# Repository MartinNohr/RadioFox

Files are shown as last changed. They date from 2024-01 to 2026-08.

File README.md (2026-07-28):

# RadioFox
Ham Radio Fox Software
This is the code for a TTGO T-Display running an SA818V radio. It is used for fox/bunny hunting.
This code requires the phoneDTMF library from here:
https://github.com/Adrianotiger/phoneDTMF
Install as documents/arduino/libraries/phoneDTMF

7/1/2026 The code has been changed to use VS Code with the pio extension loaded. Load the dtmf file into the VS Code lib folder.
The code also now uses espressif version 3.x instead of 2.x. They had introduced a number of breaking changes in version 3.x that resulted in numerous code changes.

7/28/2026 I went back to core 2.0.17. The 3.x one rebooted constantly. I'll spend some time later figureing out why.

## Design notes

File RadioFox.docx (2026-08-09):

# Radio Fox

Using TTGO T1 (T-Display)

# 1 Introduction

## 1.1 Radio Fox History

There is a hobby among amateur radio enthusiasts (AKA Hams) that is known as fox hunting or sometimes as bunny hunting. It is played by hiding a transmitter that transmits periodically and is then silent until it is time to transmit again. This cycle repeats. Teams use radio receivers with directional antennas to find the transmitter. The technique is called triangulation. The first team to find the transmitter wins. Sometimes the transmitter is moved periodically to make the game more challenging, this is called a walking fox.

Many of these radios are homemade using handheld radios and timers. This device is a single PCB (printed circuit board) using an esp32 (Arduino) computer with a display. There are two 18650 batteries with a charging circuit and an SA818 shortwave transceiver module on the PCB. A rotary push button dial is used to set the various parameters for the fox. These parameters include transmit time, pause time, frequency settings, audio, morse code ID, various other radio settings, and a variety of system settings for the fox device.

The Bionics company manufactures several types of Fox radios. I had never heard of them until I had this project working, so I can’t claim to be inspired by any of their designs. Sven Schumacher (VE6IDK) proposed this project to me in 2023, at which time I suggested using the TTGO T-Display esp32 module. I had used this device in a previous project, my Magic Image Wand, so I already had a nice menu system that would be easy to adapt to this project. It also featured code to handle a micro-SD card which could be used to store configuration files and music/tone files.

A link to this file can be found here: https://www.youtube.com/watch?v=oTXZL2KgMQE

## 1.2 Antenna

Any 50-ohm antenna designed for the VHF range is acceptable. Please remember to connect the antenna before transmitting, it is safest to have the proper load connected to the radio chip. You can also connect a 50-ohm dummy load for testing purposes to avoid sending radio waves out into the air!

## 1.3 Initial Setup

The first thing to enter is the Call Sign. Remember that you should not be transmitting without sending your call sign out periodically. The radio cycles between Call Sign and Beacon (whatever text you want) and the audio if a file has been selected. The audio can be wav, mp3, or the txt files which generate tones. The Beacon and Call Sign are sent out as morse code. A future revision of the PCB is being considered that will have an audio chip so higher quality sound recordings can be sent. The speed and pitch of the morse code can be adjusted.

The Beacon text is often something that will identify this radio, especially if there are more fox radios in the same neighborhood.

## 1.4 Charging Issues

The device is charged using the USB-C connector. There is a flaw on the PCB that requires a USB-A to USB-C cable. This has been fixed in version 1.11 of the PCB so that USB-C to USB-C cables will also work.

## 1.5 Beacon Mode

Version 1.06 adds a beacon mode that limits the allowed frequency range. The system must be powered by an external power supply connected to the USB C charging port if you want it to keep running for days, weeks or longer. This Beacon mode should not be confused with the Beacon text that is transmitted periodically.

## 1.6 Source Code

The firmware source code consists of C and C++. The source code can be found at MartinNohr/RadioFox: Ham Radio Fox Software (https://github.com/MartinNohr/RadioFox)

VS Code IDE with the pioarduino extension is used for compiling the code. The libraries used are listed in the platformio.ini file.

If you just want to flash the bin files from the GitHub site, I have tried several websites, and this one worked the best: ESP Terminator | Browser-Based Firmware Flasher (https://espterminator.com/)

Use the factory bin file for versions before 1.15. The factory file can actually be used anytime. The other bin file is for loading from the SD card.

Steps for using the flash website:

1. Select ESP32
2. Select Device and then select serial port
3. Connect device, it should show connected and the screen will change
4. Select firmware file (the factory one)
5. On the right panel find “flash firmware” and click it
6. Wait patiently, it takes a minute or two
7. Click on “disconnect” button on the left side.

### 1.6.1 Radio Firmware Versions

Version 1.15

- Fixed the update firmware command. It was unfortunately broken in previous versions. It can only be updated by flashing everything. The factory bin file is required for this since the partition table has been changed. The factory bin file is called ./firmware/firmware.factory.bin. This file contains all the partition information, the bootloader and the app code. Use ESP Terminator | Browser-Based Firmware Flasher (https://espterminator.com/) to upload everything. You can also send the esp32 back to me and I will program it for free, just include the postage.

Version 1.14

- Added ability to play WAV and MP3 files. Removed the immediate txstop option as it could leave the audio player in an untidy state. Updated some libraries to the latest versions.

Version 1.13

- Ported the code to espressif core 3.x instead of requiring 2.0.17.

Version 1.12

- Moved latitude and longitude menu items to be right below the “Send GPS:” menu item. They were below the “TX:” menu which was confusing. The TX frequency item was moved right below the TX Power and before the beacon mode item.
- I also corrected the documentation that the power output is 1 or 0.5 Watts for high and low power settings.

Version 1.11

- Added ability to send manually entered GPS coordinates when in beacon mode.

Version 1.10

- Added main menu entries to return to the main run screen. The long press still works.

Version 1.09

- Moved the active time display to the end of the second line on the main display. Bug 32, when the audio file was selected, the last line overwrote the bottom of the display.

Version 1.08

- Show the active run time on the main display in hours, minutes, and seconds. This time is reset on boot, and just keeps track of the time used for sending and pausing.

Version 1.07

- Change "Beacon Frequency Mode" in menus to "Beacon Frequency".

Version 1.06

- Added a switch to limit the frequency range to that allowed for beacon use in ITU region 2. The range is 144.276-144.300 MHz.

Version 1.05

- Added adjustable morse pitch, from 300 to 3000 Hz.

Version 1.04

- Fixed crash when no SD card found.

Version 1.03

- Fixed hang problem #26. Short TX time and B0 pressed caused the display to stop updating.

Version 1.02

- Changed prompts from BTN0/1 to B0/1 to match the labels on the case.

Version 1.01

- Made TX red dot larger. Show DTMF characters in green on the bottom. (not tested yet).

Version 1.00

- This is the initial version when this document was first created. The software is considered mostly complete.

# 2 The Hardware

## 2.1 PCB

The Fox is a single PCB that includes an 18650 battery holder that can have 1 or 2 batteries. You can choose 1 or 2 since they are connected in parallel. The button top style batteries are required. The flat top batteries will not work. Also note that the size standard is not always followed and some batteries will not fit. If that is the case try a different pair. The best batteries I have found are from www.liionwholesale.com. The batteries I use are found here: Protected 3400mAh 10A 18650 Button Top Battery - Wholesale Discount – Liion Wholesale Batteries (https://liionwholesale.com/collections/batteries/products/protected-3400mah-10a-18650-button-top-battery-wholesale-discount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) .

There is a USB C connector on the left edge used for charging the batteries. Above that is a micro-SD slot. The SD card holds tone files and saved settings files. It can also be used to load new firmware onto the TTGO chip. There is also a USB C connector on the TTGO. It is used for downloading firmware or debugging operations. It might also be used for serial communications in a future firmware release. It is not used for charging the batteries.

## 2.2 Radio

The radio functions are handled by the SA818-V on the top right. There are vents in the case to allow cooling as this module can become quite hot when transmitting at high power for longer timer intervals. Transmitting longer than one minute is not recommended. High power is about 1W and low power is about 0.5W. These powers are according to the data sheet and may not be entirely accurate. I have not measured them with a power meter. Make sure a suitable antenna is connected to avoid damage to the radio circuit.

## 2.3 Batteries

The 18650 batteries must be button top style and protection is recommended. The 18650 battery length is a very loose standard, and some batteries may not fit. Too long and they cannot be used. Too short, it might be possible to bend the contacts on the battery holder negative side. The battery holder is polarized to prevent insertion in the wrong direction. Do not defeat the feature or magic blue smoke may appear from the PCB!

## 2.4 Micro SD Card

The SD card holds the tone, mp3, and wav files. You can also put the RadioFox.bin file on there for updating the firmware. Note that updating only works for version 1.15 and later. The latest firmware file is found on the GitHub site. It is at ./firmware/firmware.bin and must be renamed on the SD card to RadioFox.bin. See the notes above on version 1.15 and the source code for more information.

Note that the SD card is limited to 32GB. This is a function of the espressif core code for handling files. We hope this will be updated at some point.

# 3 Run Time

The actual runtime depends on the transmitting time and quality of the batteries. There are many deceptively labelled 18650 batteries available. The best ones I have found are made by Panasonic and Sanyo. Using 1 minute transmit, 4 minutes pause, low power setting, and display dimming the Fox Radio ran for 12 hours using Panasonic batteries.

# 4 Tone Files

The tone files are used to play “music” during transmissions. This can be used to identify the Fox, or just to annoy people!

The files are saved as .TXT and simply contain a list of tones to be played. The format is similar the hard coded files from here: robsoncouto/arduino-songs (github.com) (https://github.com/robsoncouto/arduino-songs/tree/master)

The Robson GitHub site has many other example tone files. They are arrays in code but are easily converted to the required text format. Give the file a name and save it on the SD card.

## 4.1 Example Tone File

This is the Tetris theme music

there are two values per note (pitch and duration)

make sure each token ends with a ','

and that the data starts with the tilde which must not be in these comments

LENGTH, %val can be used to set the length of the note, it defaults to 90% and 10% quiet after the note

This can be used for pizzicato notes, LENGTH, 25, for example

~

TEMPO, 145,

LENGTH, 90,

NOTE_E5, 4, NOTE_B4, 8, NOTE_C5, 8, NOTE_D5, 4, NOTE_C5, 8, NOTE_B4, 8,

NOTE_A4, 4, NOTE_A4, 8, NOTE_C5, 8, NOTE_E5, 4, NOTE_D5, 8, NOTE_C5, 8,

NOTE_B4, -4, NOTE_C5, 8, NOTE_D5, 4, NOTE_E5, 4,

NOTE_C5, 4, NOTE_A4, 4, NOTE_A4, 8, NOTE_A4, 4, NOTE_B4, 8, NOTE_C5, 8,

NOTE_D5, -4, NOTE_F5, 8, NOTE_A5, 4, NOTE_G5, 8, NOTE_F5, 8,

NOTE_E5, -4, NOTE_C5, 8, NOTE_E5, 4, NOTE_D5, 8, NOTE_C5, 8,

NOTE_B4, 4, NOTE_B4, 8, NOTE_C5, 8, NOTE_D5, 4, NOTE_E5, 4,

NOTE_C5, 4, NOTE_A4, 4, NOTE_A4, 4, REST, 4,

# 5 Audio Files

It is possible to play MP3 or WAV files instead of the tone files. They are selected through the same menu selection. The radio uses PDM (pulse density modulation) to encode the audio. This is not the best audio quality, but it does allow the use of the existing board design. Better quality would require a proper sound chip on the PCB. This may be done in the future.

# 6 Updating Firmware

The new file must be put on the SD card and named RadioFox.bin. The file is found on the github site in the firmware folder, it is named firmware.bin, it must be renamed and copied to the micro SD card. The system menu has an entry New Version BIN file that will attempt to load this file. Confirmation will be required from the dial, After loading the BIN file can optionally be erased.

There is another file there named firmware.factory.bin. It contains the partition settings needed to update pre 1.15 versions, which are not bin file updateable. It will be necessary to use an esp32 flash program. I have only done this from platformio, but there are probably other ways. Send the esp32 to me and I will update it and send it back. Please include postage!

# 7 DTMF Operations

DTMF (aka touch-tones) can be sent from the transmitter to control certain operations of the radio. It works best when the tones are sent for at least a second. It is usually also necessary to wait 2 seconds after pressing the transmit button on the radio. All commands consist of a ‘*’ followed by a digit. The following commands are available.

Please feel free to request additional commands. I’m sure there are other usual things that can be done remotely using DTMF signals. Also note that these functions have not yet been tested extensively so there may be some bugs in the code. I will fix as soon as I can after I find out what they are.

## 7.1 DTMF *1

Start transmitting timer.

## 7.2 DTMF *2

Stop transmitting timer.

## 7.3 DTMF *4

Set low power mode.

## 7.4 DTMF *5

Set high power mode.

## 7.5 DTMF *6

Cancel existing delay and pause and begin transmitting immediately.

# 8 Button Operations

All operations can be controlled by the rotary push button on the box and the two extra buttons to the left labelled B0 and B1. A long press is used to access the menu system and is done by holding the button down for about a ½ second or longer. This long press time is also adjustable if a longer or shorter time is preferred. The system has two modes of operation. After booting the display shows the radio status and some important radio settings.

A long press on the dial or a simple press on B1 will open the menus. The system opens the last menu that was used. A long press or B1 in the menus returns to the normal radio mode. Each menu except the main menu has two entries, the first and the last, which will return to the previous menu.

Many data entry screens will show help on the bottom few lines to explain the button functions.

## 8.1 Dedicated Buttons – Button0(B0) and Button1(B1)

There are two dedicated buttons on the top left of the TTGO device. They are accessible from the top of the case. The top one is called B0 and the bottom one is called B1. Both these buttons support both clicking and long presses. A long press of B0 and B1 together will reboot the system. The function of these buttons depends on the current operating mode as described next. Common to all modes is that clicking B1 will always emulate a long press of the dial button.

### 8.1.1 B0/B1 During Run Mode

B0 toggles the run state to stop or start transmitting mode. Long B0 cancels the current transmit or pause timer. B1 enters the menu system.

### 8.1.2 B0/B1 During Menu Mode

B0 returns to the previous menu. It does nothing if at the top menu. Long B0 displays some help (if available) about the current menu item. Note that currently only a few menu items have help. More will be added in the future.

B1 acts the same as long pressing the dial button.

### 8.1.3 B0/B1 During Integer Entry

B0 cycles through the allowed increment values. For example, if the range is 1 to 1000, the increment from the dial will be 1. After a dial click the increment will change to 10 and dial will add and subtract values by 10. Another click will change the increment to 100. Long B0 resets the value to the original value. B1 or long dial click saves the new value and closes the number entry screen.

## 8.2 Rotating Dial and Clicking Button

Dial rotation is only useful in the menu system, it doesn’t have any function while the radio status is displayed. In menu mode the dial menu selects items, and changes settings. In the menus, boolean values toggle with each click. Multiple selections cycle through all the available options. Integer values go to another screen that shows the minimum and maximum values. Rotating the dial right increases the value while rotating to the left decreases it by the increment amount. The increment amount can be changed by clicking the button which will cycle between different values. One of the values will be a reset to the original value, activated with a long press. A long press is also used to accept the new value and return to the menu. A * or highlight indicates the active menu line. A + in front of the menu means another menu will be activated. Any menu item starting with ‘-‘ goes back to the previous menu when clicked. A dial long press will return to radio status mode. The current menu entry is remembered so that it will return to the same place when the long press is done from the radio status mode.

### 8.2.1 Button Menu Operations Short Descriptions

Left/ Right

Select menu

Select file or list values

Inc/ Dec integers

Long press

Open menu system, goes to the remembered menu point

Return to radio mode, the current menu point is remembered

Accept integer

Choose filenames

Click

Select menu item, including return to previous menu

Toggle booleans

Cycle through multiple selections

Cancel filename or list selections

# 9 Main Operating Screen

After booting or when not in the menu system the radio status is displayed. It shows the current operation, the count of transmit cycles, the ID text, any selected audio file, the transmit frequency and the receive frequency offset. The bottom of the screen shows the battery status on the right if it has been enabled. This is related to the current battery voltage and will drop while transmitting. There are also 4 LED’s on the PCB that can be seen through the slot on the side of the case. These LED’s are controlled by the battery charger circuit and indicate the battery status during running and charging.

During transmitting the bottom left shows an animated red dot. In a future firmware update the received DTMF characters will be display next to this.

# 10 Menu Details

The following sections detail each entry in all of the menus starting with the main or top menu. A ‘+’ at the start indicates that this is a sub-menu and will open more menu selections when clicked. Menu items that have a ‘:’ after the name will show options separated by ‘|’ or a ‘-‘ to indicate a range. Values in italic are alphanumeric sequences. An example is the radio ID. Some menu entries may depend on other menu items settings. For example the audio file name menu item is hidden unless “Play Audio File” is Yes.

## 10.1 +Radio Settings

### 10.1.1 XMIT: On|Off

This must be set to On for the radio to begin transmitting. If saved as On then the radio will start sending right after booting. If it is Off it will not automatically start sending. It can be toggled with the B0 button while in run mode. Using B0 does not changed

### 10.1.2 TX Power: High|Low

High power is about 1W and low power is 0.5W. These are the only values allowed by the SA818 radio. If lower power is desired an attenuator can be attached to the radio antenna.

### 10.1.3 TX: 134-174 MHz or 144.275-144.300 (beacon mode only)

This is the transmit VHF frequency. A future version might be created using the UHF radio module. VHF is more common for Fox Hunting.

### 10.1.4 Beacon Mode: Yes|No

This restricts the frequency range to the allowed values for ITU region 2.

### 10.1.5 Send GPS: Yes|NO (beacon mode only)

This enables sending the GPS latitude and longitude values. The values must be entered manually from a phone or GPS device. A future version of the hardware may have a built-in GPS module or it may be able to connect to a serial GPS device using the USB connection.

### 10.1.6 Latitude: +/-n.nnnnnn (Send GPS Yes only)

Enter the current latitude by reading it from a phone or GPS unit.

### 10.1.7 Longitude: +/-n.nnnnnn (Send GPS Yes only)

Enter the current longitude by reading it from a phone or GPS unit.

### 10.1.8 Beacon ID: text

This is an alphanumeric string sent out during the transmitting cycle as morse code. It is always sent right before the Call Sign (ID). The beacon text may be empty.

### 10.1.9 Call Sign: text

This alphanumeric string is sent out after the beacon text. It is sent as morse code. It is legally required to send this ID string periodically so it must not be empty and should be a valid FCC amateur radio ID. It is usually set to the ID of the person setting up the radio.

### 10.1.10 Play Audio File: Yes|No

This allows the selected tone file to be played after the beacon and call sign are sent.

### 10.1.11 Audio File: filename

This menu item is only visible if the previous item is set to Yes. Clicking the dial will list all of the *.txt files on the SD card. The dial is rotated to highlight a file and a long press will set it. Note that a click of dial just exits the list of file with no selection being performed.

### 10.1.12 Morse Interval: 50-500 mS

This sets the speed of the morse code sent using the Beacon and Call Sign values. Lower values are faster, larger values are slower.

## 10.2 +Radio Timers

### 10.2.1 Start Delay: 0-120 Min

When B0 or the menu starts the transmit mode the system will not actually begin sending until this time is expired. This allows the radio to be hidden and gives the hiding person time to leave the area and return before transmission starts.

### 10.2.2 Timer Mode: Fixed|Random

In Fixed mode the sending time and pause timer are controlled by the Send and Pause values and are always the same. In Random mode the transmit time and pause time are randomly chosen from the allowed values set in the Min and Max values for TX Send and Pause. This makes the timing less predictable and make the game a little bit harder. Keep your ears on!

### 10.2.3 TX Send: 10-90 Sec

Fixed time for transmission. Shorter times are more challenging to locate but use less battery energy. Longer times overheat the radio and use more battery energy. If this time is set to less than the total ID+Call+Audio time then there will be only one cycle of data transmitted. If the time is longer then the ID+Call+Audio cycles will be repeated until the time has expired. Note that both ID and Audio will always be completed before transmission ends.

### 10.2.4 TX Pause:10-1200 Sec

This is the pause between transmissions. Longer times let the radio cool off and save the battery for longer run times.

### 10.2.5 TX Send Min: 10-90 Sec

In random mode this is the minimum send time.

### 10.2.6 TX Send Max: 10-90 Sec

In random mode this is the maximum send time.

### 10.2.7 TX Pause Min: 10-1200 Sec

In random mode this is the minimum pause time.

### 10.2.8 TX Pause Max: 10-1200 Sec

In random mode this is the maximum pause time.

### 10.2.9 Radio Pause: Sleep|Awake

During pause time the radio can be put into sleep mode. This lowers the power consumption and lets the battery last longer. However note that this also means that the DTMF commands are disabled since the radio is asleep!

## 10.3 +More Radio Settings

### 10.3.1 RX Offset: -600|0|+600 kHz

This is the frequency offset from the transmit frequency that the radio uses to receive DTMF commands. An offset is recommended. If 0 is used the radio will only listen when it isn’t sending. It has not been tested if it listens during sending when the offset is not 0.

### 10.3.2 Bandwidth: 12.5|25 kHz

This sets the radio bandwidth. It has not been tested much to see what effect it has on performance yet.

### 10.3.3 CTCSS/DCS: CTCSS|DCS

This sets the un-squelch values for either the analog or digital versions.

### 10.3.4 TX CTCSS: None|67-250.3

Analog un-squelch frequencies sent out.

### 10.3.5 RX CTCSS: None|67-250.3

Analog un-squelch frequency for receiving.

### 10.3.6 TX DCS: None|023-754

Digital un-squelch value for sending.

### 10.3.7 TX I/N: I|N

The digital I or N value for sending.

### 10.3.8 RX DCS: None|023-754

Digital un-squelch value for receiving.

### 10.3.9 RX I/N: I|N

The digital I or N value for receiving.

### 10.3.10 RX Volume: 1-6

This is the receive volume setting. It affects how well DTMF tones are detected.

### 10.3.11 RX Squelch: 0-8

This affects how much signal is required to receive the DTMF signals.

## 10.4 Cancel Waits/TX Now

When the radio is in either send or pause mode this command will cancel the timer and the next mode will start. For example, if you want to cancel the pause and go to transmit, use this option. It can also be done by long pressing B0.

## 10.5 +Saved Settings Files

Saved settings files are named files stored on the SD card. They are useful to quickly configure the radio for different uses. All values except the battery calibration are affected.

### 10.5.1 Create File

This prompts the user for a name. The file is then created using the current system settings.

### 10.5.2 Save/Update File

This command saves the current settings into the selected file. If it already exists the user will be asked to confirm overwriting the file.

### 10.5.3 Load File

This command asks the user for the name and then sets all of the system settings except the battery calibration using the values in the file.

### 10.5.4 Delete File

The user selects a file from the list and then it can be deleted.

## 10.6 +System Settings

### 10.6.1 +Display Settings

#### 10.6.1.1 Dimming Mode: None|Timer

The display can be set to dim automatically after a specified number of seconds. This is used to save battery power since the backlight uses a significant amount.

#### 10.6.1.2 Bright Value: 1-100%

Set the display brightness value.

#### 10.6.1.3 Dim Value: 0-100%

Set the display brightness after the timer below expires.

#### 10.6.1.4 Display Dim Time: 0-120 S

Specify the time until the display changes to dim mode.

#### 10.6.1.5 +Sideways Scroll Settings

Lines of text that too long for the display will scroll back and forth. The following settings control the speed.

##### 10.6.1.5.1 Speed: 1-1000 mS

Controls the speed of text moving to the left.

##### 10.6.1.5.2 Pause: 1-100 mS

This controls the pause when the text is at the end (all the way to the left).

##### 10.6.1.5.3 Reverse Speed: 1-20x

This is how fast the text scrolls back to the beginning (to the right). 2x means twice as fast as the text scrolled to the left.

#### 10.6.1.6 Menu Selection: Color|*

Menu selections and selections from a list can be either colored or marked with the ‘*’ character.

#### 10.6.1.7 Text/HiLite Colors

This selection allows for choosing the colors of the text and the highlight. The background screen is always black.

### 10.6.2 +Dial & Button Settings

#### 10.6.2.1 Direction: Normal:Reverse

If you really want the button to be the other way around this is the choice for you.

#### 10.6.2.2 Long Press Timer: 2-200

This value affects how long or short a long press is. The default value is normally OK, but somebody might want to change it.

### 10.6.3 +Battery Settings

Since the PCB was designed with 10% resistors for measuring the battery voltage some calibration is needed. A future PCB will probably use better resistors so this won’t be needed.

#### 10.6.3.1 Show Battery: Yes|No

This option controls the battery display on the bottom right of the display.

#### 10.6.3.2 Full Battery: 2000-4000

This is the value that indicates a full 4.2V battery.

#### 10.6.3.3 Set Full Battery

This selection reads the current battery values and stores it. It is best set by fully charging the battery and then disconnecting the charger. Wait a couple of minutes and then use it several times until it seems stable.

#### 10.6.3.4 Read Battery Raw Data

This continuously reads the battery value. It was originally used for testing, but it seems like it might possibly be useful so it was left in the menu system.

### 10.6.4 New Version BIN File

New firmware can be loaded by putting the binary file on the SD card. It must be named RadioFox.BIN. There are two prompts, one to confirm overwriting the firmware, and another to allow deletion of the BIN file after installation.

### 10.6.5 Factory Settings

This command resets all settings except the high battery value to the original factory values. The factory reset can also be done by holding the dial button down while turning the power on.

### 10.6.6 Format EEPROM

This will clear and reset the eeprom where the settings are save in non-volatile memory. This is how settings are saved while the system is not powered.

## 10.7 Save Current Settings

This stores all of the current settings in the non-volatile memory. Note that this is not often used since settings are normally saved each time they are changed.

## 10.8 Reboot

This causes the system to reboot. It will wait 2 seconds first. If you press the dial during the reboot factory settings will be restored. Note that the battery full settings will not be reset.

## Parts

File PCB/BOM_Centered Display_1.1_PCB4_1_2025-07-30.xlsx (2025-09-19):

No. | Quantity | Comment | Designator | Footprint | Value | Manufacturer Part | Manufacturer | Supplier Part | Supplier
1 | 5 | 10uF | C1,C2,C6,C7,C17 | C1206 | 10uF | 1206F106Z160CT | Walsin(华新科) | C396769 | LCSC
2 | 4 | 22uF | C3,C4,C5,C26 | C1206 | 22uF | CL31F226ZPHNNNE | SAMSUNG(三星) | C159749 | LCSC
3 | 1 | 100nF | C8 | C0603 | 100nF | CL10B104KC8NNNC | SAMSUNG(三星) | C15725 | LCSC
4 | 1 | 100nF | C9 | C0402 | 100nF | GRM155R71H104KE14D | muRata(村田) | C77020 | LCSC
5 | 3 | 47nF | C22,C23,C24 | C0402 | 47nF | CGA2B2X5R1E473K050BA | TDK | C3889999 | LCSC
6 | 1 | 10nF | C25 | C0402 | 10nF | C1005X7R1H103KT000E | TDK | C694170 | LCSC
7 | 1 | DM3AT-SF-PEJM5 | CARD1 | SD-SMD_DM3AT-SF-PEJM5 |  | DM3AT-SF-PEJM5 | HRS(广濑) | C114218 | LCSC
8 | 1 | PH2.0-2P-LT | CN1 | conn-smd_ph2.0-1x2pw |  | PH2.0-2P-LT | CAX(创都) | C722761 | LCSC
9 | 1 | BSMD1812-250-8V | F2 | F1812 |  | BSMD1812-250-8V | BHFUSE(佰宏) | C960027 | LCSC
10 | 2 | A2541HWV-12P | H1,H2 | HDR-TH_12P-P2.54-V-F |  | A2541HWV-12P | CJT(长江连接器) | C225509 | LCSC
11 | 1 | 1uH | L1 | IND-SMD_L5.4-W5.1_SPM5020 | 1uH | SPM5015T-1R0M-LR | TDK | C1329923 | LCSC
12 | 4 | MHS171WDT-C2 | LED1,LED2,LED3,LED4 | LED-SMD_L2.0-W1.1-R-RD-SIDE_WHITE |  | MHS171WDT-C2 | MEIHUA(美华) | C693902 | LCSC
13 | 2 | 2N7002_R1_00001 | Q4,Q5 | SOT-23-3_L2.9-W1.3-P1.90-LS2.4-BR |  | 2N7002_R1_00001 | PANJIT(强茂) | C282260 | LCSC
14 | 1 | 2Ω | R1 | r0402 | 2Ω | ERJ2GEJ2R0X | PANASONIC(松下) | C412896 | LCSC
15 | 1 | 2Ω | R2 | R0402 | 2Ω | ERJ2GEJ2R0X | PANASONIC(松下) | C412896 | LCSC
16 | 1 | 43kΩ | R3 | R0402 | 43kΩ | RC0402FR-0743KL | YAGEO(国巨) | C185415 | LCSC
17 | 3 | 100kΩ | R4,R14,R15 | R0402 | 100kΩ | RC0402FR-07100KL | YAGEO(国巨) | C60491 | LCSC
18 | 6 | 20kΩ | R5,R6,R7,R8,R9,R10 | R0402 | 20kΩ | RC0402FR-0720KL | YAGEO(国巨) | C93942 | LCSC
19 | 3 | 10kΩ | R11,R12,R18 | R0402 | 10kΩ | RC0402FR-0710KL | YAGEO(国巨) | C60490 | LCSC
20 | 1 | 47kΩ | R13 | R0402 | 47kΩ | RC0402FR-0747KL | YAGEO(国巨) | C93943 | LCSC
21 | 2 | 47kΩ | R16,R17 | R0402 | 47kΩ | MCR01MZPF4702 | ROHM(罗姆) | C2837787 | LCSC
22 | 4 | 510Ω | R19,R20,R21,R22 | R0603 | 510Ω | RC0603FR-07510RL | YAGEO(国巨) | C114670 | LCSC
23 | 2 | 5.1kΩ | R23,R24 | R0402 | 5.1kΩ | 0402WGF5101TCE | UNI-ROYAL(厚声) | C25905 | LCSC
24 | 1 | KH-SMA-P-8496 | RF1 | SMA-TH_KH-SMA-P-8496 |  | KH-SMA-P-8496 | kinghelm(金航标) | C910123 | LCSC
25 | 1 | PEC11R-4220F-S0012 | SW1 | SW-TH_PEC11R-4220F-S0012 |  | PEC11R-4220F-S0012 | BOURNS | C143817 | LCSC
26 | 1 | TS-1187A-B-A-B | SW3 | SW-SMD_4P-L5.1-W5.1-P3.70-LS6.5-TL-2 |  | TS-1187A-B-A-B | XKB Connectivity(中国星坤) | C318884 | LCSC
27 | 1 | SS-12D11L5 | SW4 | SW-TH_SS-12D11L5 |  | SS-12D11L5 | XKB Connectivity(中国星坤) | C319010 | LCSC
28 | 1 | IP5306 | U1 | ESOP-8_L4.9-W3.9-P1.27-LS6.0-BL-EP |  | IP5306 | INJOINIC(英集芯) | C181692 | LCSC
29 | 1 | SA818S-V | U2 | WIRELM-SMD_G-NICERF_SA818S-X |  | SA818S-V | G-NiceRF(思为无线) | SA818S-V | NiceRF.com
30 | 1 | 1049P | U3 | BAT_1049P |  | 1049P | Keystone Electronics |  | digikey.com
31 | 1 | YTC-TC16-473 | USB1 | USB-SMD_YTC-TC16-473 |  | YTC-TC16-473 | YIYUAN(怡远) | C5329561 | LCSC

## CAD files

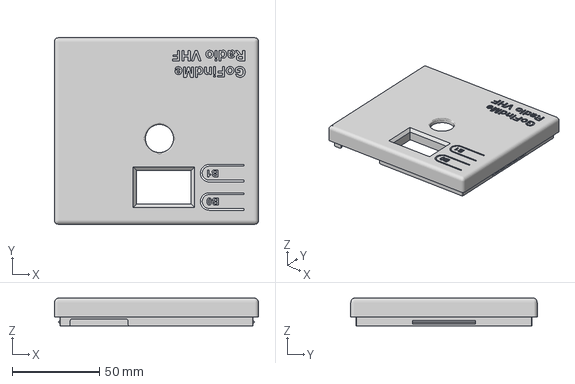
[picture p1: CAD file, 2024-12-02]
design/FoxCaseTop.3mf
116.6 x 106.6 x 16.0 mm

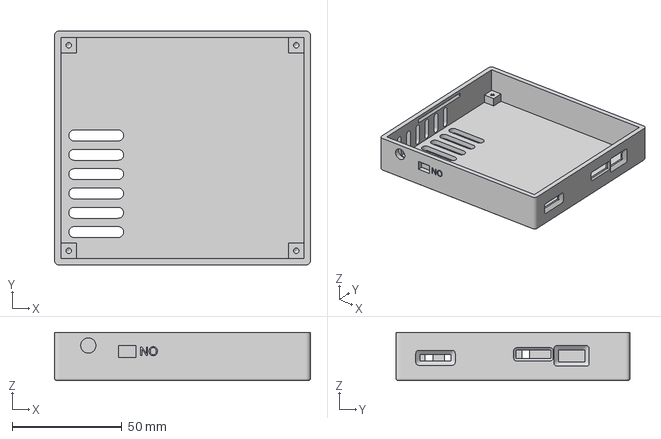
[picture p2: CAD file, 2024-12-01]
design/FoxCaseBottom.3mf
116.6 x 106.6 x 22.0 mm

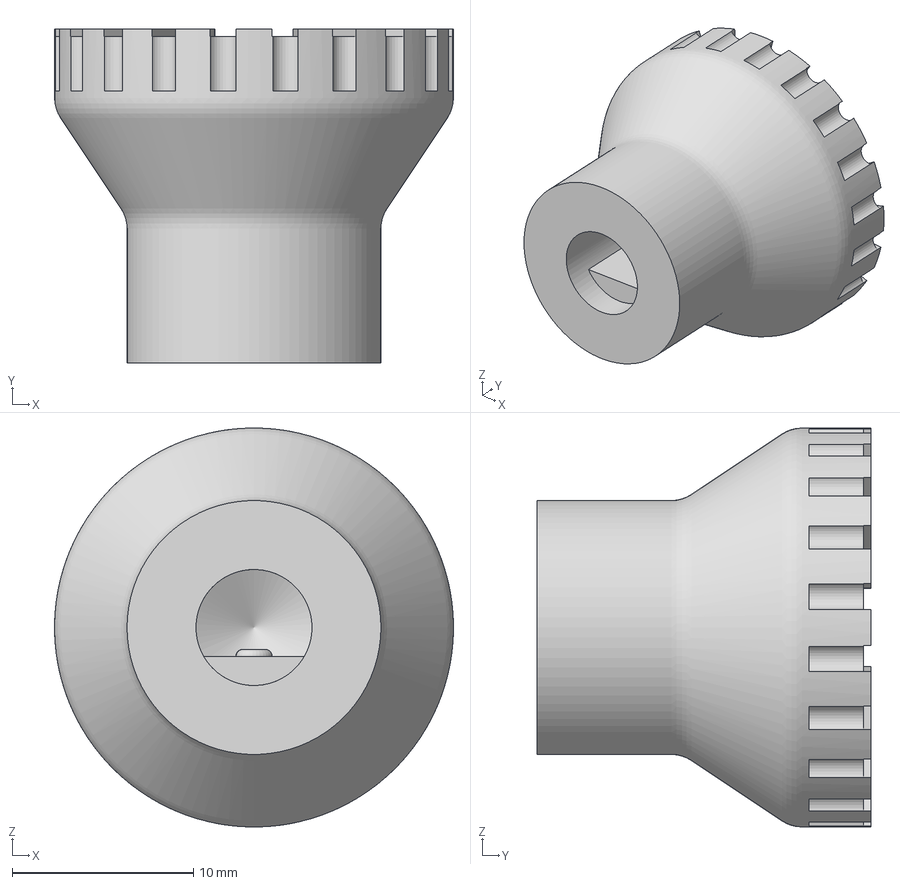
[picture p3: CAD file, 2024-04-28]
design/Dial Button.3mf
22.0 x 18.4 x 22.0 mm

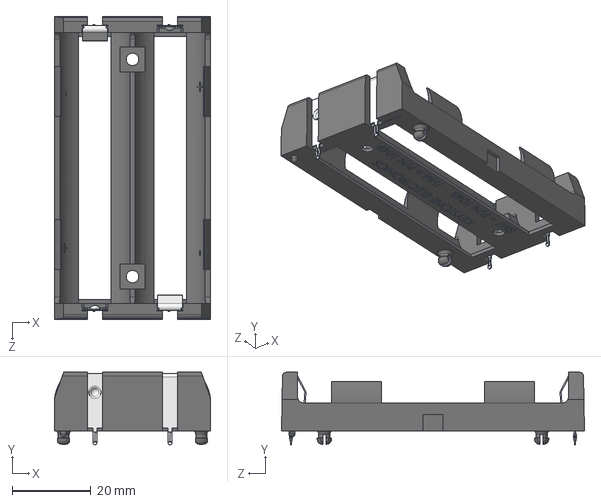
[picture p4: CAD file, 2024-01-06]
design/1049P.step
39.8 x 18.5 x 77.1 mm

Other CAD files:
design/case v57.f3d

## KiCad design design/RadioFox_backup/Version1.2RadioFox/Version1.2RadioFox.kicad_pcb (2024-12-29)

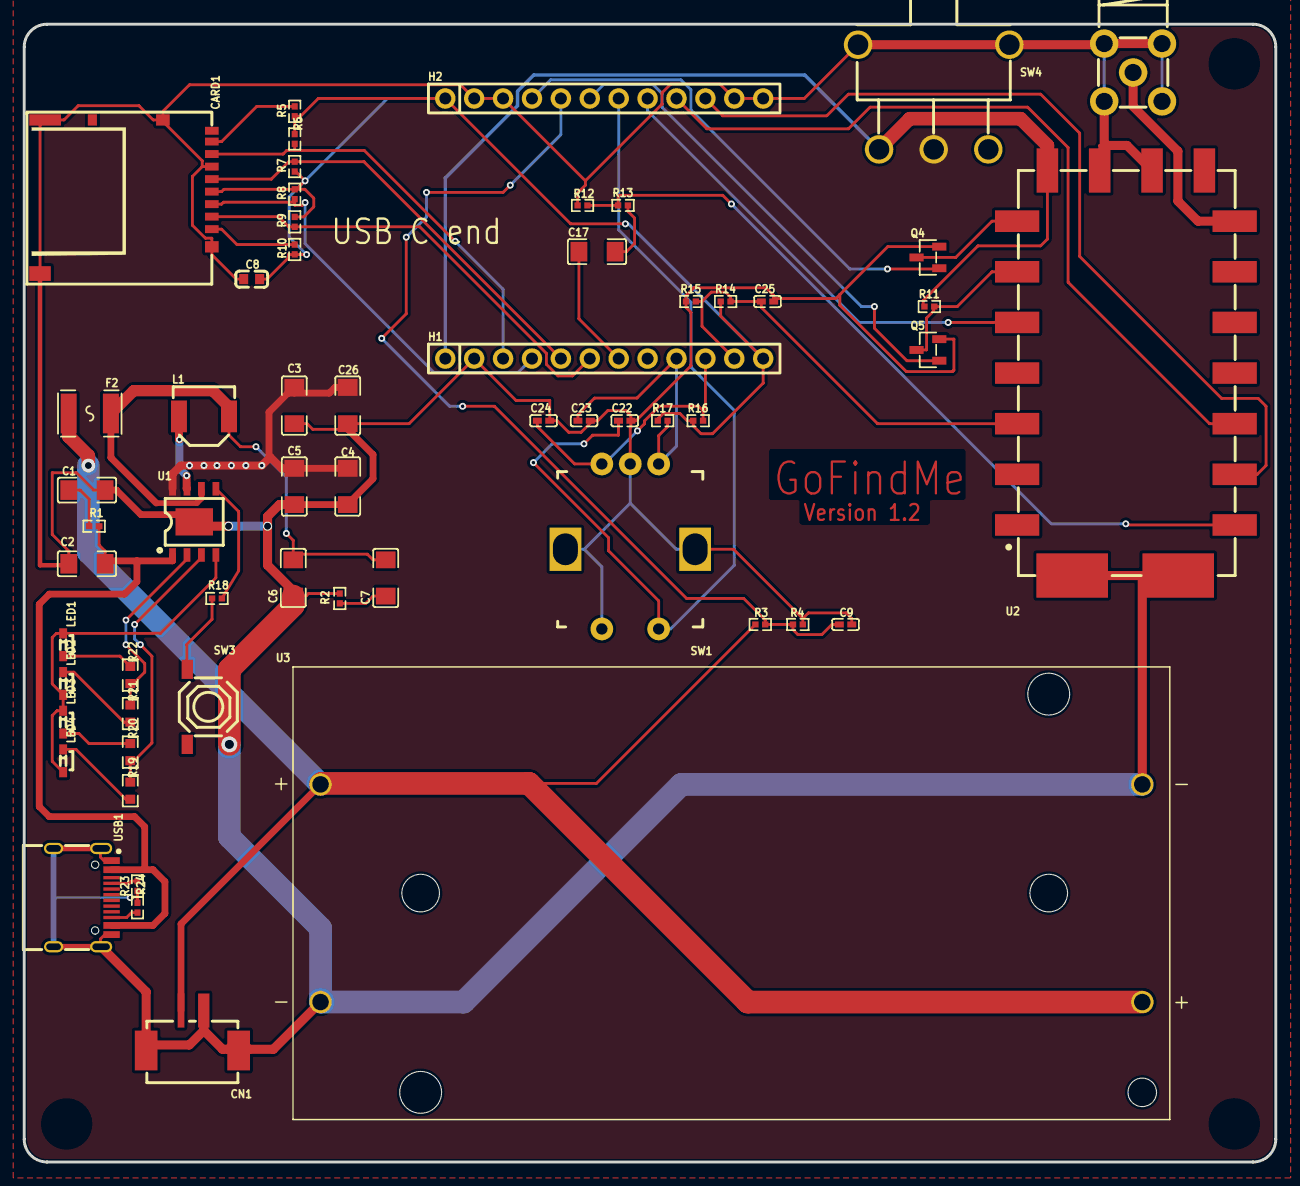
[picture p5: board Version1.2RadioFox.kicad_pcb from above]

Board: 2 copper layers, 110.0 x 100.0 mm, 59 parts (0 on the bottom side), 43 nets.

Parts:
C1, C2, C3, C4, C5, C6, C7, C17, C26: C1206
C8: C0603
C9, C22, C23, C24, C25: C0402
CARD1: SD-SMD_DM3AT-SF-PEJM5
CN1: conn-smd_ph2.0-1x2pw
F2: F1812
H1, H2: HDR-TH_12P-P2.54-V-F
L1: IND-SMD_L5.4-W5.1_SPM5020
LED1, LED2, LED3, LED4: LED-SMD_L2.0-W1.1-R-RD-SIDE_WHITE
Q4, Q5: SOT-23-3_L2.9-W1.3-P1.90-LS2.4-BR
R1: r0402
R2, R3, R4, R5, R6, R7, R8, R9, R10, R11, R12, R13, R14, R15, R16, R17, R18, R23, R24: R0402
R19, R20, R21, R22: R0603
RF1: SMA-TH_KH-SMA-P-8496
SW1: sw-th_pec11r-4220f-s0012
SW3: SW-SMD_4P-L5.1-W5.1-P3.70-LS6.5-TL-2
SW4: SW-TH_SS-12D11L5
U1: ESOP-8_L4.9-W3.9-P1.27-LS6.0-BL-EP
U2: WIRELM-SMD_G-NICERF_SA818S-X
U3: BAT_1049P
USB1: USB-SMD_YTC-TC16-473

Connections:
3V3: C8.1, CARD1.4, H1.12, H2.1, R5.1, R6.1, R7.1, R8.1, R9.1, R10.1, R14.1, R16.1, R17.1
5V: H1.1, R11.1, SW4.1, U2.8
5VREG: C3.1, C4.1, C5.1, C26.1, SW4.2, U1.8
$2N118: CARD1.7, H1.3, R6.2
$2N119: CARD1.3, H1.4, R8.2
$2N120: CARD1.5, H1.5, R7.2
$2N121: CARD1.8, R5.2
$2N122: CARD1.2, H1.6, R9.2
$2N123: CARD1.1, R10.2
$2N921: C1.2, R1.1
$2N930: R12.1, R13.1, U2.18
$2N934: C17.2, R13.2
$2N9497: C7.1, R2.1
$2N10454: L1.1, U1.7
$2N10458: C6.2, C7.2, F2.1, L1.2, U1.6
$2N33469: R18.1, SW3.2
$2N33473: R18.2, U1.5
$2N85905: LED1.1, R22.1
$2N85915: LED2.2, R21.1
$2N85988: LED3.1, R20.1
$2N85990: LED4.2, R19.1
$2N93035: R24.2, USB1.B5
$2N93039: R23.2, USB1.A5
AF_OUT: C25.1, H1.11, R14.2, R15.2, U2.3
ANT: RF1.5, U2.12
BATLEVELSENSE: C9.2, H2.5, R3.2, R4.1
GND: C1.1, C2.1, C3.2, C4.2, C5.2, C6.1, C8.2, C9.1, C22.2, C23.2, C24.2, C25.2, C26.2, CARD1.6, CARD1.10, CARD1.12, CARD1.13, CARD1.14, CN1.1, CN1.3, CN1.4, H1.2, H2.2, H2.3, H2.11, H2.12, Q4.2, Q5.2, R2.2, R4.2, R12.2, R15.1, R23.1, R24.1, RF1.1, RF1.2, RF1.3, RF1.4, SW1.2, SW1.3, SW1.C, SW3.3, SW3.4, SW4.4, SW4.5, U1.9, U2.9, U2.10, U2.19, U2.20, U3.2, U3.3, USB1.1, USB1.2, USB1.3, USB1.4, USB1.A1B12, USB1.B1A12
H/L: Q4.3, U2.7
H/L_SIG: H2.4, Q4.1
LED1: R21.2, R22.2, U1.2
LED2: R19.2, R20.2, U1.3
LED3: LED1.2, LED2.1, LED3.2, LED4.1, U1.4
MIC-INPUT: C17.1, H1.7
POWER: C2.2, R1.2, U1.1, USB1.A4B9, USB1.B4A9
PTT: H2.8, U2.5
RADIO_SLEEP: Q5.3, R11.2, U2.6
RX_RF: H2.9, U2.16
SLEEP_CONTROL: H2.6, Q5.1
SW1: C22.1, H2.7, SW1.1
SWA: C23.1, H1.9, R17.2, SW1.A
SWB: C24.1, H1.10, R16.2, SW1.B
TX_RF: H2.10, U2.17
VBAT+: CN1.2, F2.2, R3.1, U3.1, U3.4

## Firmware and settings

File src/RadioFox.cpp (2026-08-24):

/*
 Name:		RadioFox.ino
 Created:	3/25/2023 8:37:33 AM
 Author:	Sven Schumacher & Martin Nohr
 Call Sign: VE6IDK & KK7JTE
*/
#include <Arduino.h>
#include "RadioFox.h"
#include <PhoneDTMF.h>
#include "pitches.h"
#include <EEPROM.h>
#include "AudioFileSourceSPIFFS.h"
#include "AudioFileSourceSD.h"
#include "AudioFileSourceID3.h"
#include "AudioGeneratorMP3.h"
#include "AudioGeneratorWAV.h"
#include "AudioOutputI2SNoDAC.h"

AudioGeneratorMP3 *audioMP3 = nullptr;
AudioGeneratorWAV *audioWav = nullptr;
AudioFileSourceSPIFFS *file = nullptr;
AudioFileSourceSD *audioSource = nullptr;
AudioOutputI2SNoDAC *audioOut = nullptr;
AudioFileSourceID3 *id3 = nullptr;

PhoneDTMF dtmf = PhoneDTMF();

// Called when a metadata event occurs (i.e. an ID3 tag, an ICY block, etc.
void MDCallback(void *cbData, const char *type, bool isUnicode, const char *string)
{
	(void)cbData;
	Serial.printf("ID3 callback for: %s = '", type);

	if (isUnicode)
	{
		string += 2;
	}

	while (*string)
	{
		char a = *(string++);
		if (isUnicode)
		{
			string++;
		}
		Serial.printf("%c", a);
	}
	Serial.printf("'\n");
	Serial.flush();
}

// timer called every second
void periodic_Second_timer_callback(void *arg)
{
	if (SystemInfo.eDisplayDimMode == DISPLAY_DIM_MODE_TIME && displayDimTimer)
	{
		--displayDimTimer;
		if (displayDimTimer == 0)
		{
			displayDimNow = true;
		}
	}
}

// handle the sideways scrolling of long lines
void TaskScrollSideways(void *params)
{
	// use this to make task run every second
	TickType_t xLastWakeTime;
	const TickType_t xFrequency = pdMS_TO_TICKS(SystemInfo.nSidewayScrollSpeed);
	// Initialize the xLastWakeTime variable with the current time.
	xLastWakeTime = xTaskGetTickCount();
	for (;;)
	{
		for (int ix = 0; ix < nMenuLineCount; ++ix)
		{
			// see if we need to restart because the screen was cleared
			if (ulTaskNotifyTake(pdTRUE, 0) != 0)
			{
				break;
			}
			int offset = TextLines[ix].nRollOffset;
			if (TextLines[ix].nRollLength)
			{
				if (TextLines[ix].nRollOffset == 0 && TextLines[ix].nRollDirection == 0)
				{
					TextLines[ix].nRollDirection = SystemInfo.nSidewaysScrollPause;
					continue;
				}
				if (TextLines[ix].nRollDirection > 1)
				{
					--TextLines[ix].nRollDirection;
				}
				if (TextLines[ix].nRollDirection == 1)
				{
					++TextLines[ix].nRollOffset;
				}
				if (TextLines[ix].nRollOffset >= (TextLines[ix].nRollLength - tft.width()) && TextLines[ix].nRollDirection > 0)
				{
					TextLines[ix].nRollDirection = -SystemInfo.nSidewaysScrollPause;
				}
				if (TextLines[ix].nRollDirection < -1)
				{
					++TextLines[ix].nRollDirection;
				}
				if (TextLines[ix].nRollDirection == -1)
				{
					TextLines[ix].nRollOffset -= SystemInfo.nSidewaysScrollReverse;
					if (TextLines[ix].nRollOffset < 0)
					{
						TextLines[ix].nRollOffset = 0;
					}
					if (TextLines[ix].nRollOffset == 0)
					{
						TextLines[ix].nRollDirection = 0;
					}
				}
				if (offset != TextLines[ix].nRollOffset)
				{
					DisplayLine(ix, TextLines[ix].Line, TextLines[ix].foreColor, TextLines[ix].backColor);
				}
			}
		}
		// Wait for the next cycle.
		vTaskDelayUntil(&xLastWakeTime, xFrequency);
	}
}

// send the latitude and longitude
void TaskSendGPS(void *parameter)
{
	ledcAttach(AUDIO_OUT_PORT, SystemInfo.nBuzzerFrequency, 8);
	// format the latitude and longitude
	String sendThese[2];
	// format the values of Lat and Long
	char tmp[40];
	sprintf(tmp, "Lat%.6f", SystemInfo.fLatitude);
	sendThese[0] = tmp;
	sprintf(tmp, "Long%.6f", SystemInfo.fLongitude);
	sendThese[1] = tmp;
	for (String str : sendThese)
	{
		for (char ch : str)
		{
			sendLetter(ch);
		}
		if (!IsTransmitting)
		{
			break;
		}
	}
	ledcDetach(AUDIO_OUT_PORT);
	// terminate this task
	TaskSendGpsHandle = NULL;
	vTaskDelete(NULL);
}

// send the radio id followed by the callsign
void TaskSendRadio(void *parameter)
{
	// take copies in case they get changed while we are here
	String sendThese[2];
	sendThese[0] = SystemInfo.cRadioString;
	sendThese[1] = SystemInfo.cRadioCallSign;
	ledcAttach(AUDIO_OUT_PORT, SystemInfo.nBuzzerFrequency, 8);
	for (String str : sendThese)
	{
		for (char ch : str)
		{
			sendLetter(ch);
		}
		if (!IsTransmitting)
		{
			break;
		}
	}
	ledcDetach(AUDIO_OUT_PORT);
	// terminate this task
	TaskSendRadioHandle = NULL;
	vTaskDelete(NULL);
}

// task to send the music or audio
void TaskSendMusic(void *parameter)
{
	String sFullName = SystemInfo.cAudioFile;
	// SD needs a full qualified path
	if (sFullName[0] != '/')
		sFullName = "/" + sFullName;
	if (SD.exists(sFullName))
	{
		vTaskDelay(pdMS_TO_TICKS(1000));
		// open the audio file and start reading lines from it
		File audioFile;
		audioFile = SD.open(sFullName);
		String ext = sFullName.substring(sFullName.length() - 3);
		ext.toUpperCase();
		if (ext == "TXT")
		{
			if (audioFile)
			{
				ledcAttach(AUDIO_OUT_PORT, SystemInfo.nBuzzerFrequency, 8);
				// put some defaults in just in case they are missing in the music file
				int noteLength = 90;
				int tempo = 145;
				// this holds the duration of a whole note in ms (60s/tempo)*4 beats
				int wholenote = (60000 * 4) / tempo;
				// first read until the ~ which marks the start of the data stream
				audioFile.readStringUntil('~');
				// read tokens until done
				String key, value;
				while ((key = audioFile.readStringUntil(',')))
				{
					// clean the key
					key.trim();
					key.toUpperCase();
					// next get the value
					value = audioFile.readStringUntil(',');
					value.trim();
					// if empty must be missing value, give up
					if (value.isEmpty())
						break;
					// check for tempo setting
					if (key.equals("TEMPO"))
					{
						// set the tempo
						tempo = value.toInt();
						wholenote = (60000 * 4) / tempo;
					}
					else if (key.equals("LENGTH"))
					{
						noteLength = value.toInt();
					}
					else
					{
						// process the notes and durations
						int note = mapNotes[key.c_str()];
						int divider = value.toInt();
						int duration = wholenote / divider;
						// negative duration means times 1.5 (dotted note)
						if (duration < 0)
						{
							// dotted notes are represented with negative durations!!
							duration *= -1.5;
						}
						// we only play the note for noteLength % of the duration, leaving the rest as a pause
						ledcWriteTone(AUDIO_OUT_PORT, note);
						vTaskDelay(pdMS_TO_TICKS((float)duration * noteLength / 100.0));
						ledcWriteTone(AUDIO_OUT_PORT, 0);
						vTaskDelay(pdMS_TO_TICKS((float)duration * ((100 - noteLength) / 100.0)));
					}
				}
				ledcDetach(AUDIO_OUT_PORT);
				audioFile.close();
			}
		}
		else if (ext == "WAV")
		{
			audioSource = new AudioFileSourceSD(sFullName.c_str());
			audioOut = new AudioOutputI2SNoDAC(32);
			audioWav = new AudioGeneratorWAV();
			audioWav->begin(audioSource, audioOut);
			// play until done
			bool bDone = false;
			while (!bDone)
			{
				if (audioWav->isRunning())
				{
					if (!audioWav->loop())
					{
						// Serial.printf("WAV stopped\n");
						audioWav->stop();
						bDone = true;
					}
				}
				vTaskDelay(pdMS_TO_TICKS(5));
			}
			if (audioSource)
				audioSource->close();
			// clean up just in case
			delete audioWav;
			audioWav = nullptr;
			delete audioSource;
			audioSource = nullptr;
			delete audioOut;
			audioOut = nullptr;
		}
		else if (ext == "MP3")
		{
			audioSource = new AudioFileSourceSD(sFullName.c_str());
			// audioSource->RegisterMetadataCB(MDCallback, (void *)"ID3TAG");
			audioOut = new AudioOutputI2SNoDAC(32);
			audioMP3 = new AudioGeneratorMP3();
			audioMP3->begin(audioSource, audioOut);
			// play until done
			bool bDone = false;
			while (!bDone)
			{
				if (audioMP3->isRunning())
				{
					if (!audioMP3->loop())
					{
						// Serial.printf("MP3 stopped\n");
						audioMP3->stop();
						bDone = true;
					}
				}
				vTaskDelay(pdMS_TO_TICKS(5));
			}
			if (audioSource)
				audioSource->close();
			// clean up just in case
			delete audioMP3;
			audioMP3 = nullptr;
			delete audioSource;
			audioSource = nullptr;
			delete audioOut;
			audioOut = nullptr;
		}
	}
	// terminate this task
	TaskSendMusicHandle = NULL;
	vTaskDelete(NULL);
}

// this controls the radio sending operations
void TaskRunTransmit(void *parameter)
{
	if (IsTransmitEnabled && IsRadioReady)
	{
		gpio_set_level((gpio_num_t)PTT_PORT, PTT_TALK);
		xEventGroupSetBits(gRadioEventsHandle, RadioEventIsTransmitting);
	}
	xTaskNotify(TaskRunRadioHandle, (uint32_t)"TX Start", eSetValueWithOverwrite);
	// wait for PTT to take effect
	vTaskDelay(pdMS_TO_TICKS(500));
	// a list of our tasks to run
	static const struct RFTaskEntry
	{
		const char *name;
		void (*task)(void *pArgs);
		TaskHandle_t *pTaskHandle;
		bool *bRunThis1; // NULL to always run, else a boolean address
		bool *bRunThis2; // if this is here, they must both be true
	} RFTaskList[] = {
		{"ID+Call", TaskSendRadio, &TaskSendRadioHandle, NULL, NULL},
		{"GPS", TaskSendGPS, &TaskSendGpsHandle, &SystemInfo.bBeaconMode, &SystemInfo.bSendGPS},
		{"Audio", TaskSendMusic, &TaskSendMusicHandle, &SystemInfo.bPlayAudioFile, NULL},
	};
	bool bDone = false;
	while (IsRadioReady && IsTransmitEnabled && !bDone && ulTaskNotifyTake(pdTRUE, 0) == 0)
	{
		int nLoopCount = 0;
		for (const struct RFTaskEntry &pte : RFTaskList)
		{
			bool b1 = pte.bRunThis1 ? *pte.bRunThis1 : true;
			bool b2 = pte.bRunThis2 ? *pte.bRunThis2 : true;
			// see if this should be run, NULL or *true means do it
			if (b1 && b2)
			{
				// send the name for display
				xTaskNotify(TaskRunRadioHandle, (uint32_t)pte.name, eSetValueWithOverwrite);
				// start the task
				xTaskCreate(pte.task, pte.name, 6000, NULL, 6, pte.pTaskHandle);
				// wait for it to complete or be cancelled
				while (*pte.pTaskHandle)
				{
					// // check for timeout or cancel task
					// if (SystemInfo.bStopImmediately && ulTaskNotifyTake(pdTRUE, 0))
					// {
					// 	if (*pte.pTaskHandle)
					// 		vTaskDelete(*pte.pTaskHandle);
					// 	*pte.pTaskHandle = NULL;
					// 	bDone = true;
					// 	break;
					// }
					vTaskDelay(pdMS_TO_TICKS(100));
				}
				if (bDone || !IsTransmitEnabled)
					break;
			}
			++nLoopCount;
		}
		vTaskDelay(pdMS_TO_TICKS(500));
	}
	// Turn off the output tone also
	ledcWriteTone(AUDIO_OUT_PORT, 0);
	// turn PTT off here
	gpio_set_level((gpio_num_t)PTT_PORT, PTT_LISTEN);
	xEventGroupClearBits(gRadioEventsHandle, RadioEventIsTransmitting);
	// stop this task after clearing the handle
	TaskRunTransmitHandle = NULL;
	vTaskDelete(NULL);
	// int freestack = uxTaskGetStackHighWaterMark(NULL);
	// Serial.println(String("xmit high water: ") + freestack);
}

// return random between two numbers, including both of them
int GetRandomBetween(int one, int two)
{
	int delta = abs(one - two);
	++delta; // include the larger one
	return (rand() % delta) + min(one, two);
}

// return the next tx time
int NextTxTime()
{
	return SystemInfo.bUseFixedTimers ? SystemInfo.nTxTimeFixed : GetRandomBetween(SystemInfo.nTxTimeMin, SystemInfo.nTxTimeMax);
}

// return the next pause time
int NextPauseTime()
{
	return SystemInfo.bUseFixedTimers ? SystemInfo.nTxPauseFixed : GetRandomBetween(SystemInfo.nTxPauseMin, SystemInfo.nTxPauseMax);
}

// all the timing and screen display is done here
void TaskRunRadio(void *parameter)
{
	// init the random generator used for timers
	srand(analogRead(BATTERY_SENSOR_GPIO));
	const char *cStatusText = NULL;
	uint32_t status = 0;
	bool bTransmitting = false;
	int secondsLeft = 0;
	int txCount = 0;
	bool bWaitingForStop = false;
	bool bWasXmit = false;
	// use this to make task run every second
	TickType_t xLastWakeTime;
	// run every second
	const TickType_t xFrequency = pdMS_TO_TICKS(1000);
	// Initialize the xLastWakeTime variable with the current time.
	xLastWakeTime = xTaskGetTickCount();
	int delayedSeconds = 0;
	// keep the time we transmit and pause in here
	unsigned long TxTime = 0;
	while (true)
	{
		if (IsTransmitEnabled)
		{
			++TxTime;
		}
		if (!IsRadioReady && bWasXmit)
		{
			// stop the radio
			delayedSeconds = secondsLeft = 0;
		}
		if (IsTransmitEnabled || TaskRunTransmitHandle)
		{
			bool bTx = IsTransmitEnabled;
			if (bWasXmit != IsTransmitEnabled)
			{
				// tell the xmitter to stop
				if (TaskRunTransmitHandle && bWasXmit)
					xTaskNotify(TaskRunTransmitHandle, 1, eSetValueWithOverwrite);
				// set if we were xmitting
				bWaitingForStop = bWasXmit;
				// don't do this code again until the bXmit flag actually changes
				bWasXmit = IsTransmitEnabled;
				// make sure we start right away or after the delay specified
				secondsLeft = 0;
				if (SystemInfo.nStartDelayTimer)
				{
					delayedSeconds = SystemInfo.nStartDelayTimer * 60;
				}
			}
			// see if the timer has run out and we need to change state
			if (secondsLeft == 0 && delayedSeconds == 0)
			{
				bTransmitting = !bTransmitting;
				if (bTransmitting)
				{
					bWaitingForStop = false;
					// start the xmitter task, only one copy to be safe
					if (TaskRunTransmitHandle == NULL)
					{
						if (SystemInfo.bSleepWhilePausing)
						{
							RadioEnable(true);
							vTaskDelay(pdMS_TO_TICKS(250));
						}
						xTaskCreate(TaskRunTransmit, "XMITFOX", 2000, NULL, 2, &TaskRunTransmitHandle);
					}
					// wait for it to start and let us know
					int nWaitCounter = 50;
					while ((status = ulTaskNotifyTake(pdTRUE, 0)) == 0)
					{
						vTaskDelay(pdMS_TO_TICKS(10));
						if (--nWaitCounter <= 0)
						{
							break;
						}
					}
					// it must be a string they sent us
					cStatusText = (const char *)status;
					txCount++;
					secondsLeft = NextTxTime();
				}
				else
				{
					// tell the xmitter to stop
					if (TaskRunTransmitHandle)
						xTaskNotify(TaskRunTransmitHandle, 1, eSetValueWithOverwrite);
					vTaskDelay(pdMS_TO_TICKS(2));
					bWaitingForStop = true;
					// -1 keeps us waiting
					secondsLeft = -1;
					delayedSeconds = 0;
				}
			}
			// see if the task sent us anything
			status = ulTaskNotifyTake(pdTRUE, 0);
			// check if this is a string pointer
			if (status)
			{
				cStatusText = (const char *)status;
			}
		}
		if (bWaitingForStop)
		{
			// check if the xmitter is finished
			if (!TaskRunTransmitHandle)
			{
				bWaitingForStop = false;
				secondsLeft = NextPauseTime();
				// sleep radio if required
				if (SystemInfo.bSleepWhilePausing)
				{
					RadioEnable(false);
				}
			}
		}
		// some logic to get the correct status message
		if (!IsTransmitEnabled)
			delayedSeconds = 0;
		if (delayedSeconds)
			cStatusText = "Delay";
		else if (IsTransmitEnabled && !bTransmitting && !bWaitingForStop)
			cStatusText = "Pause";
		// set string if not transmitting
		else if (!IsTransmitEnabled && !bWaitingForStop)
		{
			cStatusText = "Transmit Off";
			secondsLeft = 0;
			delayedSeconds = 0;
		}
		if (!g_bSettingsMode)
		{
			int lineNo = 0;
			char fmt[20];
			String str = cStatusText;
			if (bWaitingForStop)
			{
				str = cStatusText + String(": Stopping");
			}
			else
			{
				if (delayedSeconds)
				{
					str += String(": ") + (delayedSeconds / 60) + " Min " + (delayedSeconds % 60) + " Sec";
				}
				else if (secondsLeft)
				{
					str += String(": ") + (secondsLeft / 60) + " Min " + (secondsLeft % 60) + " Sec";
				}
			}
			if (IsRadioReady)
			{
				DisplayLine(lineNo++, str, SystemInfo.menuTextColor);
			}
			else
			{
				DisplayLine(lineNo++, "Waiting for Radio", SystemInfo.menuTextColor);
			}
			// show cycle count and time active (HH:MM)
			char tm[12];
			sprintf(tm, "%2d:%02d", (TxTime / (60 * 60)), (TxTime / 60) % 60);
			DisplayLine(lineNo++, String(String("Count: ") + txCount + "  Time: " + tm), SystemInfo.menuTextColor);
			DisplayLine(lineNo++, String(SystemInfo.cRadioString) + " " + SystemInfo.cRadioCallSign + " " + ((SystemInfo.bBeaconMode && SystemInfo.bSendGPS) ? "GPS" : ""), SystemInfo.menuTextColor);
			if (SystemInfo.bPlayAudioFile)
				DisplayLine(lineNo++, "Audio: " + String(SystemInfo.cAudioFile), SystemInfo.menuTextColor);
			sprintf(fmt, "%03d MHz ", SystemInfo.nFrequency % 1000);
			DisplayLine(lineNo++, String(SystemInfo.nFrequency / 1000) + "." + fmt + (SystemInfo.bTxPowerLow ? "Lo" : "Hi") + " Power", SystemInfo.menuTextColor);
			DisplayLine(lineNo++, String("RX Offset: ") + RxOffsetModeText[SystemInfo.nRfOffset] + " kHz", SystemInfo.menuTextColor);
		}
		if (secondsLeft > 0)
			--secondsLeft;
		if (delayedSeconds > 0)
			--delayedSeconds;
		// see if we need to cancel the pauses
		if (IsCancelWaits)
		{
			delayedSeconds = secondsLeft = 0;
			xEventGroupClearBits(gRadioEventsHandle, RadioEventCancelWaits);
		}
		// Wait for the next cycle.
		vTaskDelayUntil(&xLastWakeTime, xFrequency);
	}
}

// show the transmit animation while sending
#define TX_CIRCLE_SIZE 10
void TaskXmitDisplay(void *parameters)
{
	// use this to make task run periodically
	TickType_t xLastWakeTime;
	const TickType_t xFrequency = pdMS_TO_TICKS(500);
	// Initialize the xLastWakeTime variable with the current time.
	xLastWakeTime = xTaskGetTickCount();

	int cycle = 0;
	while (true)
	{
		if (!g_bSettingsMode)
		{
			if (xSemaphoreTake(MutexDisplayHandle, portMAX_DELAY) == pdTRUE)
			{
				cycle = cycle % TX_CIRCLE_SIZE;
				if (!IsTransmitting)
					cycle = 0;
				if (cycle)
				{
					tft.drawCircle(10, tft.height() - TX_CIRCLE_SIZE, cycle, TFT_RED);
				}
				else
				{
					tft.fillCircle(10, tft.height() - TX_CIRCLE_SIZE, TX_CIRCLE_SIZE, TFT_BLACK);
				}
				++cycle;
				xSemaphoreGive(MutexDisplayHandle);
			}
		}
		else
		{
			cycle = 0;
		}
		// Wait for the next cycle if nothing happened this time
		vTaskDelayUntil(&xLastWakeTime, xFrequency);
	}
}

// show the battery every 60 seconds
void TaskShowBattery(void *parameters)
{
	while (true)
	{
		// show battery level if on
		if (SystemInfo.bShowBatteryLevel && !g_bSettingsMode)
		{
			int raw;
			ReadBattery(&raw);
			ShowBattery(NULL);
		}
		ulTaskNotifyTake(pdTRUE, pdMS_TO_TICKS(10 * 1000));
	}
}
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
void loop()
{
	if (SystemInfo.bRunWebServer)
	{
		server.handleClient();
	}
	delay(100);
}

// Functions
void sendLetter(char c)
{
	const char *morseCodeLetter[] = {
		".-",	// A
		"-...", // B
		"-.-.", // C
		"-..",	// D
		".",	// E
		"..-.", // F
		"--.",	// G
		"....", // H
		"..",	// I
		".---", // J
		"-.-",	// K
		".-..", // L
		"--",	// M
		"-.",	// N
		"---",	// O
		".--.", // P
		"--.-", // Q
		".-.",	// R
		"...",	// S
		"-",	// T
		"..-",	// U
		"...-", // V
		".--",	// W
		"-..-", // X
		"-.--", // Y
		"--..", // Z
	};
	const char *morseCodeDigit[] = {
		"-----", // 0
		".----", // 1
		"..---", // 2
		"...--", // 3
		"....-", // 4
		".....", // 5
		"-....", // 6
		"--...", // 7
		"---..", // 8
		"----.", // 9
	};

	c = toupper(c);
	char const *pm = NULL;
	if (isalpha(c))
	{
		pm = morseCodeLetter[c - 'A'];
	}
	else if (isdigit(c))
	{
		pm = morseCodeDigit[c - '0'];
	}
	else if (c == '/')
	{
		pm = "-..-.";
	}
	else if (c == ' ')
	{
		pm = " ";
	}
	else if (c == '.')
	{
		pm = "._._._";
	}
	if (pm)
		sendMorseCode(pm);
}

void sendMorseCode(const char *tokens)
{
	int i;
	// Serial.println("Morse: " + String(tokens));
	for (i = 0; tokens[i]; ++i)
	{
		switch (tokens[i])
		{
		case '-':
			sendDash();
			break;
		case '.':
			sendDot();
			break;
		case ' ':
			sendEndOfWord();
			break;
		}
	}
	vTaskDelay(pdMS_TO_TICKS(2 * SystemInfo.nMorseInterval));
	//   Serial.print(" ");
}

void sendEndOfWord()
{
	vTaskDelay(pdMS_TO_TICKS(4 * SystemInfo.nMorseInterval));
	//   Serial.print("  ");
}

// basic functions - Morse code concepts
void sendDot()
{
	ledcWriteTone(AUDIO_OUT_PORT, SystemInfo.nBuzzerFrequency);
	vTaskDelay(pdMS_TO_TICKS(1 * SystemInfo.nMorseInterval));
	ledcWriteTone(AUDIO_OUT_PORT, 0);
	vTaskDelay(pdMS_TO_TICKS(1 * SystemInfo.nMorseInterval));
	//   Serial.print(".");
}

void sendDash()
{
	ledcWriteTone(AUDIO_OUT_PORT, SystemInfo.nBuzzerFrequency);
	vTaskDelay(pdMS_TO_TICKS(3 * SystemInfo.nMorseInterval));
	ledcWriteTone(AUDIO_OUT_PORT, 0);
	vTaskDelay(pdMS_TO_TICKS(1 * SystemInfo.nMorseInterval));
	//   Serial.print("-");
}

// enable or disable radio
void RadioEnable(bool bEnable)
{
	digitalWrite(RADIO_SLEEP_PORT, bEnable ? LOW : HIGH);
}

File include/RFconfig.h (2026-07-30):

#pragma once
// ***** Various switches for options are set here *****
// Choose UHF or VHF SA818, 0 is VHF, 1 is UHF
#define RADIO_UHF 0

// also remember to change User_Setup_Select.h correctly
// use one of these in that file
//#include <User_Setups/Setup25_TTGO_T_Display.h>    // Setup file for ESP32 and TTGO T-Display ST7789V SPI bus TFT
//#include <User_Setups/Setup206_LilyGo_T_Display_S3.h>     // For the LilyGo T-Display S3 based ESP32S3 with ST7789 170 x 320 TFT
// make sure this one is commented out
//#include <User_Setup.h>           // Default setup is root library folder

// set 1 for T-Display, 3 for S3 version
#define TTGO_T_DISPLAY 1

// battery level
#define HAS_BATTERY_LEVEL 1

#define PTT_TALK 0
#define PTT_LISTEN 1

// all the gpio pins
#if TTGO_T_DISPLAY == 1
// use this to control the LCD brightness
constexpr int TFT_ENABLE = 4;
// SD details
#define SDSckPin   25  // GIPO25
#define SDMosiPin  26  // GPIO26
#define SDMisoPin  27  // GPIO27
#define SDcsPin    33  // GPIO33
// battery sensor GPIO
#define BATTERY_SENSOR_GPIO 13
// set the push button GPIO port, tried 39, but it seems to pulse every second, somebody is using it!
#define DIAL_BTN 2
// default dial direction GPIO ports
#define DIAL_A 38
#define DIAL_B 37
#define PTT_PORT 17
#define AUDIO_IN_PORT 36
#define AUDIO_OUT_PORT 32        // send music and cw out this pin
#define TXPOWER_PORT 12	// Pin to control TX Power, not connected -> high power, connect to GND -> Low power
// the radio serial ports
#define RADIO_SLEEP_PORT 15	// LOW for awake, HIGH for sleep
#define RADIO_SERIAL_RX 21
#define RADIO_SERIAL_TX 22	// NOTE: do not use the LED_BUILTIN which is also 22, the TTGO T-Display does not have an LED
#endif

#if TTGO_T_DISPLAY == 3
// tone generator
const int toneChannel = 2;

constexpr int TFT_ENABLE = 38;
// use these to control the LCD brightness
const int freq = 5000;
const int ledChannel = 0;
const int resolution = 8;
// SD details
#define SDSckPin   12
#define SDMosiPin  13
#define SDMisoPin  11
#define SDcsPin    10
// battery sensor GPIO
#define BATTERY_SENSOR_GPIO 16
#define DIAL_BTN 3
// default dial direction GPIO ports
#define DIAL_A 1
#define DIAL_B 2
#define PTT_PORT 21
#define AUDIO_IN_PORT 44
#define AUDIO_OUT_PORT 43        // send music and cw out this pin
#define TXPOWER_PORT 21	// Pin to control TX Power, not connected -> high power, connect to GND -> Low power
// the radio serial ports
#define RADIO_SLEEP_PORT 15	// LOW for awake, HIGH for sleep *************** not available *************
#define RADIO_SERIAL_RX 18
#define RADIO_SERIAL_TX 17	// NOTE: do not use the LED_BUILTIN which is also 22, the TTGO T-Display does not have an LED
#endif

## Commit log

2023-07-09 Fixed includes and some more code.
    [RadioFox.h]
2023-07-10 Fixed some include and library issues.
    [RadioFox.h]
2023-07-11 Some work on the correct menus, added radio settings.
    [RadioFox.h]
2023-07-12 Fixed radio frequencty range and added edit radio call ID.
    [RadioFox.h]
2023-07-15 Fixed config saving/loading and menu changes.
    [RFconfig.h, RadioFox.h]
2023-07-16 Fixed scrolling for audio file selection.
    [RadioFox.h]
2023-07-16 Fixed audio file selection to hilite the current selection.
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2023-07-17 Keep the TX timer running even when in menus. Menus will delay the transmit though until exited.
2023-07-17 Fixed missing init of LCD display dim timer. Removed display main screen code, it is now a task so not needed.
    [RadioFox.h]
2023-11-23 Starting to show signs of life. Tasks are working for controlling the xmit functions. Next will be fixing the morse sending code.
    [RFconfig.h, RadioFox.h, RotaryDialButton.h]
2023-11-24 Fixed crash problem and made task stacks 4000, a more reasonable size. The crash is caused by tasks writing to the TFT which is not re-entrant. Need to add some mutexes to really fix. For now just tu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
    [RadioFox.h]
2023-11-25 Only display the battery when it changes, it seems to pause the TaskRunRadio task for 4 or 5 seconds.
2023-11-27 Many changes with tasks doing all the work now. Fixed the battery display to only run every 60 seconds, it takes a long time and messes up the run display.
    [RadioFox.h]
2023-11-27 Attempt to fix display of battery after menus, not working but don't want to lose this code.
    [RadioFox.h]
2023-11-27 Fixed updating the battery level after showing the menus.
2023-11-27 Added DTMF handler task. Changed some pins. Pin12 seems to interfere with uploading, so don't use it.
    [RFconfig.h, RadioFox.h]
2023-11-29 Switched serial output to 12, pin 22 seems to follow the morse out, don't know why yet.
2023-11-29 Changed serial radio tx to pin 22 again. There was some morse functions using LED_BUILTIN which was set to 22, but there is no LED on the TTGO board.
2023-11-30 Fixed factory reset sequence prompts, they were sometimes on a blank screen. Delayed start until the intro screen was erased.
    [RadioFox.h]
2023-12-02 Fixed sideways scrolling on menus and displays.
    [RadioFox.h]
2023-12-03 Moved scrolling and menu handling to tasks. Fixed the integer edit screen to fix the blinking of the bar, it was redrawing constantly.
    [RadioFox.h]
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2023-12-16 Fixed a stability problem with sideways scrolling. It would sometimes reboot, the task priority was too high.
    [RadioFox.h]
2023-12-26 Improvements, but still hangs sometimes after setting radio. Very strange, the dial pulses the tx power line, like something got inited wrong.
    [RadioFox.h]
2023-12-26 Moved radio power setting to start of setup code.
2023-12-26 Setup the radio when any system setting is changed, makes code easier to maintain and doesn't really hurt anything. Added menu items to select CTSS frequencies.
    [RadioFox.h]
2023-12-27 Fixed some crashing when entering beacon and id strings. Caused by not delaying to allow the watchdog to be called. There was also a chance that the id strings might be changed while being sent, if s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
    [RadioFox.h]
2023-12-27 Fixed DTMF handler, the begin needed to filter higher frequencies, set to limit at 2kHz, which will pass all DTMF. The handling code needs some improvements, but it does work now.
    [RadioFox.h]
2023-12-28 Added the Easyedapro file in the design folder. This is also where the 3D enclosure plans will be.
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2023-12-30 Fixed wiring error in the schematic.
2023-12-31 PCB layout improved, but note the batteries are backwards!
2023-12-31 Moved power supply components on the PCB to a better location.
2024-01-01 Fixed battery reverse protection, I think.
2024-01-02 Removed battery reverse detection. Made board smaller.
2024-01-02 Correct main display, high and low power were reversed.
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2024-01-03 Move H/L radio control to GPIO12, and used GPIO15 for radio sleep control. Pin 12 must be allowed to float low or the esp32 won't boot.
    [RFconfig.h]
2024-01-03 Added FET to control sleep, is isn't safe to pullup 5V on esp32 inputs according to the esp32 forum.
2024-01-04 DTMF now needs '*' to activate following commands. There is also a timer set how long commands will be accepted after '*'. This time gets set after each valid command so multiple commands can be sent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
2024-01-04 Removed debug message and changed delay limit from 0 to 120 minutes. Also tried to stop the transmission when the radio needs to be initialized, doesn't work reliably, but probably not a big deal.
    [RadioFox.h]
2024-01-05 The main screen status messages weren't always correct when a delay was set. Fixed now. Disabled wifi menu until available.
    [RadioFox.h]
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2024-01-06 Added component libraries needed by EasyEDA for the battery case component. They must be copied to the ./libraries folder of EasyEDA pro.
    [1049P.step]
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2024-01-07 Added DCS squelch unlocking codes. Fixed a bug with setting CTCSS codes, the format was wrong to the radio, needed to always be 4 characters, like "0000".
    [RadioFox.h]
2024-01-07 FIxed DTMF code to leave PTT in the same state it was in before.
    [RadioFox.h]
2024-01-08 The radio menu got too long. Rearranged things.
    [RadioFox.h]
2024-01-08 Changed display timer dim value to go from 0 to 100 instead of 1 to 100. DIsplay might as well be completely off to save a little more power.
2024-01-09 Removed useless menu entries, like number of battery cells and other things.
2024-01-09 Updated and fixed schematic. The H/L signal was accidentally shorted to ground.
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2024-01-14 Fixed the battery connection mistake from the JST connector.
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2024-01-16 Shorten the DTMF delay when the timer is active so only the first '*' takes longer. Added system menu entry to check the 5V value. Put dial button debounce back to 20mS. The noise problem was caused 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
    [RadioFox.h, RotaryDialButton.h]
2024-01-17 Fix a capacitor pad size.
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2024-01-21 Added commands to cancel any delay and pause timers so transmitting will start immediately. See #7 and #13 .
2024-01-22 BTN0Long will now cancel the current state and go the next one. e.g. if was transmitting it will go to pause, and if was pause will go to transmitting.
2024-04-02 Added ability to play music note files from the SD card. Removed the tetris music and put it on the SD card. Open one of the .txt files to see the format. Several music files were created from files 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
2024-04-05 Empty the radio rx buffer before sending. This was needed on the PCB version since the radio sends 15 nulls after power up. The String() library ReadString will store nulls and they cause indexOf to 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
2024-04-05 Flush the radio buffer before sending commands to it. The radio was sometimes not initializing after power up.
2024-04-06 Added an auto retry for a couple of times in case the radio didn't get the message during setup.
2024-04-06 Set better voltage values and removed the USB voltage display which only works on the TTGO USB port.
2024-04-16 Changed the default low battery to match the IP5306 thinking. Also fixed to compile with latest ESP32Encoder code. Changed bin file name to RadioFox.ino.ttgo-t1.bin so as not to confuse with S3 versi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
2024-04-16 Added radio sleep during pause. This will of course disable DTMF, but should save some power. Increased the sideways scrolling priority so it was smoother. Changed battery display task to 10 seconds.
2024-04-17 Set battery back to 15 seconds pause. Put more accurate values in default battery full and empty values.
2024-04-25 added 3D case design
    [FoxCaseBottom.3mf, FoxCaseTop.3mf, case v19.f3d]
2024-04-26 Fixed bezel position and improved the top mounting
    Also added screw holes for the PCB.
    [FoxCaseBottom.3mf, FoxCaseTop.3mf, case v23.f3d]
2024-04-26 Fixed the bezel position
    [FoxCaseTop.3mf, case v24.f3d]
2024-04-26 fixed the bezel chimney
    [FoxCaseTop.3mf, case v25.f3d]
2024-04-27 improved retaining lip
    [FoxCaseTop.3mf]
2024-04-27 current Fusion 360 file
    [case v26.f3d]
2024-04-27 added cooling vents
    [FoxCaseBottom.3mf, case v29.f3d]
2024-04-30 adjusted bezel for TTGO variations
    [FoxCaseTop.3mf, case v41.f3d]
2024-04-30 Made button pins .2mm longer to fit better
    [FoxCaseTop.3mf, case v42.f3d]
2024-05-01 Fixed a problem with some radios not sending. Moved the RadioSerial setup later in the code. I think the radios don't boot up correctly sometimes if the RXD line is raised too fast. Anyway, this fixe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
    [RadioFox.h]
2024-05-01 another adjustment to the bezel
    [FoxCaseTop.3mf, case v43.f3d]
2024-05-02 Added automatic battery full calibration. Initialize the battery smoother so it starts reading faster.
2024-05-02 Removed the automatic battery calibration, didn't work well. Added manual battery calibration so it can match the IP5306 chip.
    [RadioFox.h]
2024-05-03 Made battery info not affected by factory reset. Those values should never change once set.
    [RadioFox.h]
2024-05-04 Added an option for fixed or random timers for xmit and pause.
    [RadioFox.h]
2024-05-06 Added settings files. Current settings can be saved into named files that can be loaded anytime.
2024-05-09 Fixed CTCSS so it doesn't get set to index -1 when dial is clicked, which should have ignore any changes.
    [RadioFox.h]
2024-05-11 Transmit ID first, before the music, since the transmit time might not be long enough to finish the music and the ID. The ID must legally be sent! Changed a ;; to ;. oops. Fixed some wrong comments. 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
    [RadioFox.h]
2024-05-11 Added indicators to which color is being changed. Changed version to 1.00. Fixed display of hilite colors.
    [RadioFox.h]
2024-05-12 Added battery support to case top and a slot to see the charge leds.
    [FoxCaseTop.3mf, case v44.f3d]
2024-05-14 slightly smaller top battery stop
    [FoxCaseTop.stl, case v47.f3d]
2024-05-14 Slightly thinner top battery stop
    [FoxCaseTop.3mf]
2024-05-15 moved and fixed LED battery window
    [FoxCaseBottom.3mf, case v50.f3d]
2024-05-17 Fixed the hang problem. #26
    [RadioFox.h]
2024-05-21 FIxed the boot crash when no SD card is found. This was caused by the SD error code call that caused a crash. Also initialize the SD card before trying any load or save file operations.
    [RadioFox.h]
2024-05-22 hole size improvements
    [FoxCaseBottom.3mf, case v52.f3d]
2024-05-22 improved sd and usb hole sizes
    [FoxCaseBottom.3mf, case v52.f3d]
2024-05-29 Added adjustable buzzer frequency.
    [RFconfig.h, RadioFox.h]
2024-08-24 Fixed display of run time, it was on the last line when audio file was on. Moved the time to the end of the second line. #32
    [RadioFox.h]
2024-08-24 Updated 3D files.
    [FoxCaseBottom.3mf, case v52.f3d, case v53.f3d]
2024-08-25 Updated DOCX file with the USB-C cable issue.
2024-11-05 Fixed GPS floating point entry. Changed Beacon to Radio ID to avoid confusion with beacon mode.
    [RadioFox.h]
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2024-12-01 Deeper letters in the case.
    [FoxCaseBottom.3mf, FoxCaseTop.3mf, case v53.f3d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]
2024-12-02 Moved B0/B1 text away from thin hinge area.
    [FoxCaseTop.3mf, case v55.f3d]
2024-12-02 More text improvements.
    [FoxCaseTop.3mf, case v55.f3d, case v57.f3d]
2024-12-18 Moved send GPS values to right befow send GPS menu item. Moved TX frequency to right below the TX power item.
2024-12-29 Some beginning Kicad files and update docx file.
    [Version1.2RadioFox.kicad_pcb, Version1.2RadioFox.kicad_sch]
2025-05-07 PCB updates
    [Version1.2RadioFox.kicad_sch]
2025-09-19 DOCX changes describing batteries. Also the latest gerber files used for NextPCB.com.
    [BOM_Centered Display_1.1_PCB4_1_2025-07-30.xlsx, PickAndPlace_PCB4_1_2025-07-30.xlsx]
2026-06-30 Vs code version (#34)
    * VS Code version of the code
    * Changes to esp32 espressif release 3.x
    * Add files via upload
    * more updates
    * Add files via upload
    * Add files via upload
    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
2026-07-29 Compile core 2.0.17 problems fixed.
    [RFconfig.h, RadioFox.cpp, RadioFox.h]
2026-07-30 Update version to 1.14 and modify GetFileNamesFromSD function signature. Increased stack size on audio task, it blew up! Added starting support for WAV and MP3, not done yet though.
    [RadioFox.cpp, RadioFox.h]
2026-07-30 Remove debug print statement for step size adjustment in GetIntegerValue function
2026-07-30 Playing MP3 works now, but immediate stop messes it up. This is likely a problem with music files also, they won't get closed properly. Fix coming soon.
    [RadioFox.cpp]
2026-07-30 Removed stop immediately, causes problems with audio. Added a third digit to the version. Playing audio still only works once and stops the morse as well, working on this bug.
    [RadioFox.cpp, RadioFox.h]
2026-07-31 Update FOX_Version to 1.14.2 and fixed mp3 audio task management. The audio port had to be attached and detached when using it as a sound generator.
    [RadioFox.cpp, RadioFox.h]
2026-07-31 Updated rotary dial code to core 3.x pcounter driver. Updated the docx to reflect the latest code.
2026-08-01 Update FOX_Version to 1.15.0 and fix firmware update command. Change partition table handling in platformio.ini.
    [RadioFox.cpp, RadioFox.h]
